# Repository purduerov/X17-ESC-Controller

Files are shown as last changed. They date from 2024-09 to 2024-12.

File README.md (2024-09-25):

# X17-ESC-Controller
This board turns signals from the Pi into PWM signals that go to the ESC Adapter

Whenever you make a new part, download the datasheet and save it here _**and**_ with the part in the parts library

Always pull other people's changes before beginning to work
`git pull`

Be sure to push your changes after  working on them. Run:
1. `git add .` to add any files in this directory or a subdirectory
or `git add -u` to add any modified files
2. (Optional) `git clean -nX` to see what ignored files can be removed
	`git clean -fX` removes ignored files (Eagle backups)
3. `git commit -m "helpful commit message"` with a description of the work that you did
4. `git push` to push your work to github

Other helpful commands
* `git status` says information about modified and staged files
* `git log` shows the recent commits of the repository
* `git log filename.extension` show the recent commits for just that file
* `git checkout first-couple-letter-of-commit-id` lets you go back to a previous version
* `git checkout master` brings you back to the latest commit
* `git tag` lists the tags
* `git tag -a orderX -m "the version of the board placed for the X'th order"` tag a specific commit
* `git push --tags` needed to push tags to remote
* `git show orderX` show the commit log for the given tag
* `git checkout orderX` go back and interact with the files at the tagged commit

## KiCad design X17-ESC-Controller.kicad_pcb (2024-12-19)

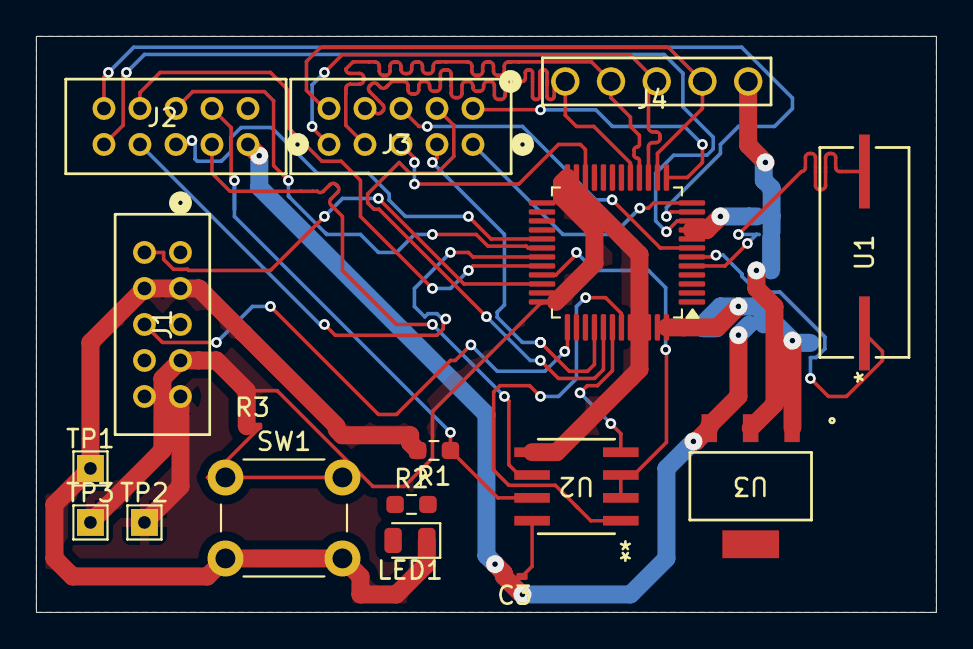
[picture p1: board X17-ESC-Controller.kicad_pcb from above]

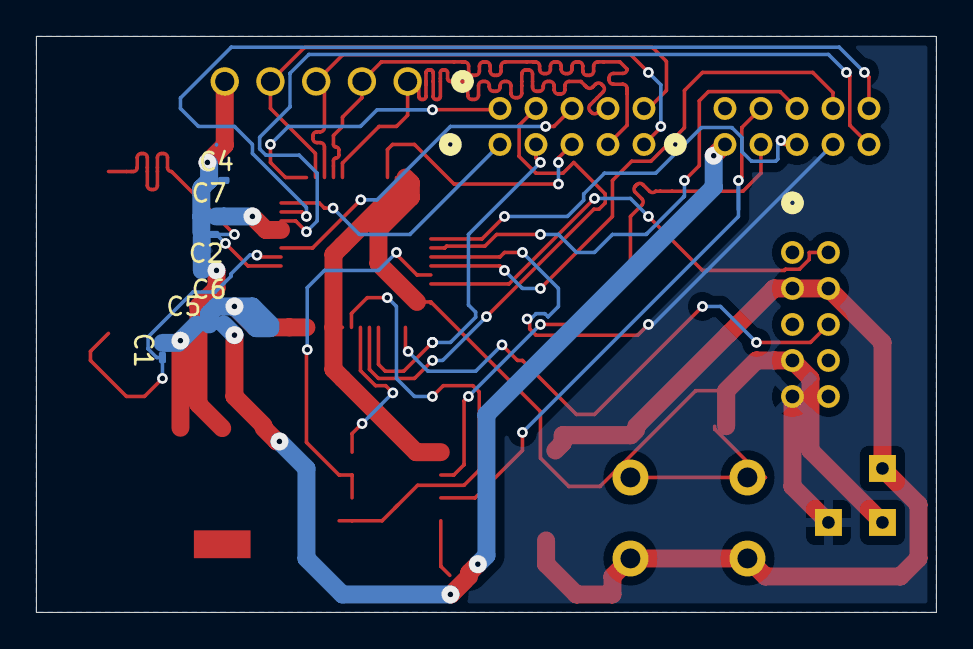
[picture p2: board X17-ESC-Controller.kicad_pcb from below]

Board: 2 copper layers, 50.0 x 32.0 mm, 23 parts (6 on the bottom side), 34 nets.

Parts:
C1, C2: 18pF; C_0201_0603Metric_Pad0.64x0.40mm_HandSolder
C3: CL10B104KB8NNWC; C_0201_0603Metric_Pad0.64x0.40mm_HandSolder
C4, C7: C; C_0201_0603Metric_Pad0.64x0.40mm_HandSolder
C5, C6: GRM188R60G226MEA0D; C_0201_0603Metric_Pad0.64x0.40mm_HandSolder
IC1: STM32F091CCT7; LQFP-48_7x7mm_P0.5mm
J1: CON10_2X5_UF_DF11_HIR
J2, J3: DF11-10DP-2DSA24; CON10_2X5_UF_DF11_HIR
J4: Conn_2Rows-05Pins; CONN_A-4030-05A_MOL
LED1: APT2012SGC; LED_0805_2012Metric
R1: 20k; R_0603_1608Metric_Pad0.98x0.95mm_HandSolder
R2: 4.2k; R_0603_1608Metric_Pad0.98x0.95mm_HandSolder
R3: 10k; R_0201_0603Metric
SW1: SW_Push; SW_PUSH_6mm
TP1, TP2, TP3: TestPoint; TestPoint_THTPad_1.5x1.5mm_Drill0.7mm
U1: 8mHz; ABLS-8.000MHZ-B2-T_ABR
U2: MAX485CSA+T; 21-0041-3-M_90-0096-8L_MXM
U3: SOT223_AZ1117I_6P5X3P5_DIO

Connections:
+3.3V: C4.2, C7.2, IC1.9 (VDDA), IC1.24 (VDD_1), IC1.36 (VDDIO2), J1.7, R3.1, TP3.1
+5.0V: J1.9, TP2.1
+5V: C3.2, C5.2, J2.1, U3.3 (INPUT)
/-3.3V: C6.1, U3.2 (OUTPUT)
/NC: IC1.1 (VBAT), IC1.2 (PC13), IC1.3 (PC14-OSC32_IN), IC1.4 (PC15-OSC32_OUT), IC1.8 (VSSA), IC1.20 (PB2), IC1.25 (PB12), IC1.26 (PB13), IC1.27 (PB14), IC1.35 (VSS_2), IC1.38 (PA15), IC1.39 (PB3), IC1.46 (PB9), IC1.47 (VSS_3), J1.1, J1.5, J1.8, J1.10
A: J2.3, U2.6 (A)
B: J2.4, R1.1, U2.7 (B)
CS: IC1.14 (PA4), J3.10, J4.4
GND: C1.2, C2.2, C4.1, C5.1, C6.2, C7.1, IC1.23 (VSS_1), IC1.44 (PF11-BOOT0), IC1.45 (PB8), IC1.48 (VDD_2), J1.3, J1.4, J4.5, LED1.1, R1.2, SW1.2, TP1.1, U2.5 (GND), U3.1 (ADJ/GND)
LED: IC1.28 (PB15), R2.1
MISO: IC1.16 (PA6), J3.7, J4.2
MOSI: IC1.17 (PA7), J3.8, J4.1
NRST: IC1.7 (NRST), J3.6, R3.2, SW1.1
unnamed: LED1.2, R2.2
unnamed: C3.1, U2.8 (VCC)
RCC_OSC_IN: C2.1, IC1.5 (PF0-OSC_IN), U1.2
RCC_OSC_OUT: C1.1, IC1.6 (PF1-OSC_OUT), U1.1
SCLK: IC1.15 (PA5), J3.9, J4.3
SWCLK: IC1.37 (PA14), J1.6
SYS_SWDIO: IC1.34 (PA13), J1.2
TIM1_CH1: IC1.29 (PA8), J2.5
TIM1_CH2: IC1.30 (PA9), J2.6
TIM1_CH3: IC1.31 (PA10), J2.7
TIM1_CH4: IC1.32 (PA11), J2.8
TIM2_CH1: IC1.10 (PA0), J2.9
TIM2_CH2: IC1.11 (PA1), J2.10
TIM2_CH3: IC1.12 (PA2), J3.1
TIM2_CH4: IC1.13 (PA3), J3.2
TIM3_CH1: IC1.40 (PB4), J3.3
TIM3_CH2: IC1.41 (PB5), J3.4
USART1_DE: IC1.33 (PA12), U2.2 (*RE), U2.3 (DE)
USART1_RX: IC1.43 (PB7), U2.1 (RO)
USART1_TX: IC1.42 (PB6), U2.4 (DI)
USART3_RX: IC1.22 (PB11), J3.5

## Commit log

2024-10-17 Add files via upload
    10/16 Schematic
    [X17-ESC-Controller.kicad_sch]
2024-10-26 X17 ESC-Controller
    ESC-Controller Schematic for Alumni Design Review
    [X17-ESC-Controller.kicad_sch]
2024-11-14 X17 Controller Schematic
    Fully updated schematic
2024-11-14 X17 ESC Controller Schematic Updated
    Updated PCB Schematic
2024-11-14 X17 ESC Controller
    Updated Schematic
2024-11-14 added board dimensions
    [X17-ESC-Controller.kicad_pcb]
2024-12-17 ESC Controller Layout
    **Before Alumni design review changes, will be updated tonight
    [X17-ESC-Controller Dec 17 7pm.kicad_pcb]
2024-12-18 PCB Layout New Component Placement
    [X17-ESC-Controller Dec 18 12am.kicad_pcb]
2024-12-18 Updated Schematic for ESC-Controller 12/18
    - Added decoupling capacitors near power pins of the microcontroller.
    - changed capacitors to 0603 capacitors
    - changed LEDs to 0805
    - changed test pads to through hole
    - made sure to label all frequencies
2024-12-18 X17-ESC-Controller 12/18
    [X17-ESC-Controller.kicad_pcb]
2024-12-19 12/17 X-17 ESC-Controller
    -Length matched signal traces (RS485, SPI, etc.)
    -Set power and ground traces to 1mm width
    -Replaced capacitors with 0603 footprint
    -Fixed capacitor footprints to match schematic
    -Added through hole test points for key signals
    -Cleaned up unnecessary wires and connections
    [X17-ESC-Controller.kicad_pcb]
